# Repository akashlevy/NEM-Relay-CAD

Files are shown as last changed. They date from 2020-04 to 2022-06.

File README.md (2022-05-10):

# Stanford Accelerate NEM Relay Models

This repository contains almost everything a researcher might need to get started with NEM relays (MEM relays): (1) a parametric layout generator with KLayout, (2) finite elment models (FEM) with COMSOL/ANSYS, (3) static/dynamic compact model generators with SPICE/Verilog-A (and validation in Mathematica), (4) scripts for characterization with Synopsys SiliconSmart to produce Liberty files for VLSI flows.

A video tutorial of the COMSOL model is available: https://www.youtube.com/watch?v=YCjhU6pspo0

Also, read this paper for more info on potential applications of these models: https://ieeexplore.ieee.org/document/9712515

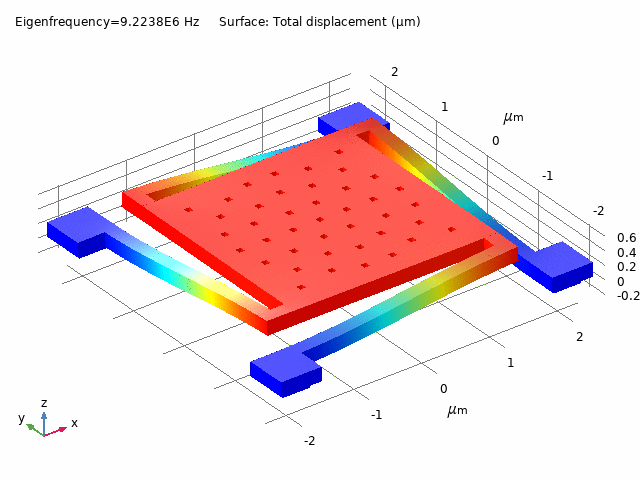
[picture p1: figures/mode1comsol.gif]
Modal Analysis in COMSOL


## Step 1: Configure NEM relay parameters

The configuration file `params.json` controls the relay dimensions and model parameters. Descriptions of the parameters are in `helper/params_desc.json`. `contpts.json` controls the locations of the contacts. To initialize contact placement to a circle, this file can be deleted.

## Step 2: KLayout NEM relay layout generator

Please use `pip install klayout` to install the Python API for KLayout. You can also install the KLayout GUI (https://www.klayout.de/), which may help with layout visualization.

Running `cd layouts; python relay.py` will generate layouts in DXF, GDSII, and CIF format based on the parameters in `params.json`. It will also generate `comsol/contpts.txt` which can be loaded into COMSOL in the next step.

You can also get predictions of the pull-in/pull-out voltages and parasitic capacitances based on the parallel-plate model by running `python handcalcs.py`. This will use the params specified in `params.json` to calculate and print these numbers.

SIDE NOTE: when we wanted to use the layout with Virtuoso, we combined layers in KLayout by doing layer operations: layer 6 = layer 6 - layer 7 + layer 8.

## Step 3: Finite element modeling (FEM)

### COMSOL model

To begin, run `python comsol_preproc.py` to generate `params.txt`. Then, load the parameters into COMSOL:
1. Under `Global Definitions/Parameters/Relay Parameters`, clear, load from file and select `comsol/params.txt`.
2. Under `Global Definitions/Parameters/Contact Placement`, clear, load from file and select `comsol/contpts.txt`.

NOTE: you may have to slightly modify the parameters once they have been loaded, since COMSOL has a bug where it does not automatically update the relay selections.

The COMSOL model has 5 studies that predict the physics of the multi-pole NEM relay. These are:
1. Spring Constant: determine spring constant by applying force to plate
2. Modal Analysis: determine eigenmodes and shapes
3. Parasitic Extraction: extract parasitic mutual capacitances between all terminals
    - A hacky way to get approximate parasitic extraction in the ON state is to set g_act = t_cont and gaptol = 1nm
4. Quasi-Static Sweep: find pull-in and pull-out voltages, contact forces, displacement contour, etc.
5. Transient Sweep: find out pull-in speed

Once these have been computed, you can view the results:
1. Mutual capacitances between all terminals
2. Eigenmode shape
3. Parasitic extraction potential plot
4. Contact placement and displacement contour plot
5. Quasi-static sweep plot
6. Transient sweep plot
7. Mechanical properties (spring constant, mass, eigenfrequencies)
8. Contact force for each contact

You can export the parameters as well for iterative contact placement and SPICE modeling.

For quasi-static sweep, you will have to choose a point on the relay to compute the displacement for. An arbitrary point on any of the contacts should work well.

For iterative contact placement, make sure to run the quasi-static sweep, then choose an operating voltage and displacement contour to extract, then export the displacement contour points. Then, run `python contpts.py` to get the next set of contacts (modify the parameters internally, if necessary, first). This generates `contpts.json`, which is used by `layouts/relay.py` to generate a new layout using the contact placement.

For SPICE modeling, make sure to run `python comsol_postproc.py`, which generates `spice/tech_params.va`. These parameters are used by the Verilog-A model.

### ANSYS model (unfinished, skip this for now)

There is an unfinished ANSYS 2020 Workbench model. It builds the NEM relay geometry using a SpaceClaim script. More work would be needed for this model to accurately predict anything, but it may serve as a good starting point/reference for people trying to model a NEM relay in ANSYS (although COMSOL is better than ANSYS at accurately modeling coupled interactions).

## Step 4: Compact modeling

### SPICE/Verilog-A model

The Verilog-A model is adapted from "Micro-Relay Technology For Energy-Efficient Integrated Circuit" (Hei Kam, Fred Chen) and is designed for use with SPECTRE or HSPICE. It has only been tested with HSPICE 2017.03, but it may also work with other SPICE simulators if simulation settings are adapted correctly.

There are three settings specific to the Verilog-A model in `params.json`. There is the Q-factor damping `Qf`, contact resistance `Rcont`, and air resistance `Rair`. These should be adjusted before simulation. All parameters are taken from the COMSOL model export: `comsol_postproc.py` must be run to generate `models/tech_params.va` that is used to define the simulation parameters.

The first thing to do is generate your Verilog-A model based on the number of bits you want to route with a single relay. You can do this by going into the `spice/` directory and running `python relay_gen.py {N}` where `N` is the number of bits to route. This will generate the Verilog-A file in the `models/` subdirectory called `nem_relay_{N}b.va` and quasistatic/transient SPICE testbenches in `test/` subdirectory. Running these simulations will verify the functionality of the relays by toggling them to see the quasistatic (slow sweep) and transient (fast sweep) response curves. Use `cscope` and export waveform data to do `plots.py` plotting.

Next, you can generate one-hot multiplexers from the NEM relays and test these as well. The first step is to run `python ohmux_gen.py {N} {M}`, where `N` is the number of bits to route, and `M` is the number of inputs to the multiplexer. This will generate several files: a SPICE model for the multiplexer without buffering (`models/nem_ohmux_{M}i_{N}b.sp`), a SPICE model for the multiplexer with an inverter to buffer the signal (`models/nem_ohmux_invd{D}_{M}i_{N}b.sp`), testbenches for both of these (`test/ohmux_test_{M}i_{N}b.sp`, `test/ohmux_test_invd{D}_{M}i_{N}b.sp`), and finally an instance file (`liberty/control/nem_ohmux_invd{D}_{M}i_{N}b.inst`) that can be used to characterize the SPICE model with SiliconSmart. By default, the inverter is taken from TSMC40 library through `tsmc40inc.sp`; using a different inverter is a matter of swapping out the implementation. The inverter drive strength can be specified through a command-line option e.g. `python ohmux_gen.py 1 2 -D1` will create a D1 inverter, and the area of a signle inverter can optionally be specified with `--area` option. The inverter area will be automatically multiplied by the number of bits to get the total area.

TODO: non-one-hot multiplexers

### Liberty model

The Liberty model generation has been tested with SiliconSmart M-2017.03-2. Library Compiler (LC) also needs to be loaded to compile the Liberty (.lib) files to DB (.db) files. In order to use SiliconSmart, first create the SPICE models in the previous step. Then simply run `siliconsmart run.tcl` to run the characterization flow. This will generate the library with all the .libs and .dbs necessary for a standard EDA flow. To debug, see the SPICE simulations for the different characterizations.

### Mathematica model (validation only)

Running the Mathematica notebook will solve the damped ODE model of the NEM relay and yield the transient displacement curve. It is good for validating the effect of Q-factor damping.

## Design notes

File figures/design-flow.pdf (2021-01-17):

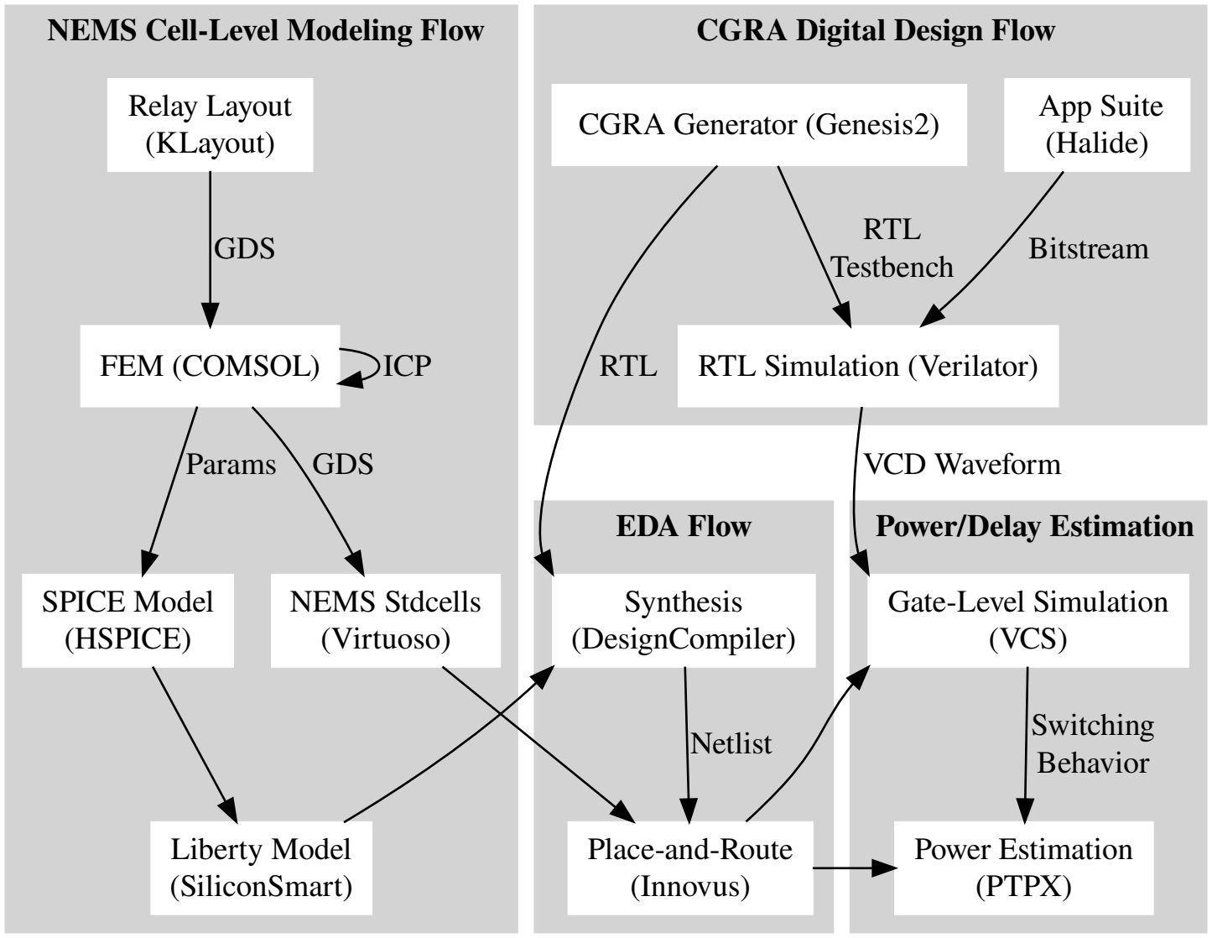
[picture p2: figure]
NEMS Cell-Level Modeling Flow; CGRA Digital Design Flow; EDA Flow; Power/Delay Estimation; Relay Layout (KLayout); FEM (COMSOL); GDS; ICP; SPICE Model (HSPICE); Params; NEMS Stdcells (Virtuoso); Liberty Model (SiliconSmart); Synthesis (DesignCompiler); Place-and-Route (Innovus); App Suite (Halide); RTL Simulation (Verilator); Bitstream; Gate-Level Simulation (VCS); VCD Waveform; CGRA Generator (Genesis2); RTL Testbench; RTL; Netlist; Power Estimation (PTPX); Switching Behavior

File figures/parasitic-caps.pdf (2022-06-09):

## Capacitance CCB:

## Capacitance CGB:

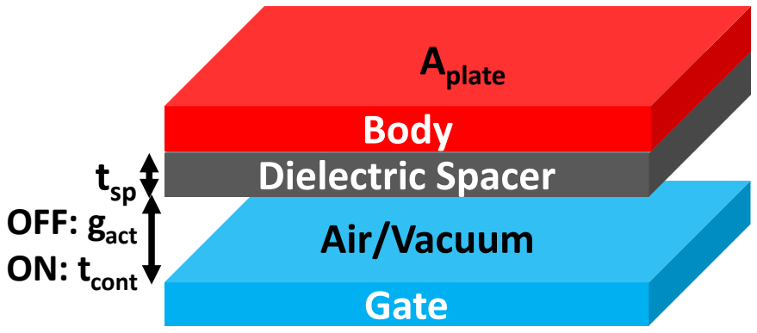
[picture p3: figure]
Gate; Dielectric Spacer; Body; OFF: gact ON: tcont; Aplate; Air/Vacuum; tsp
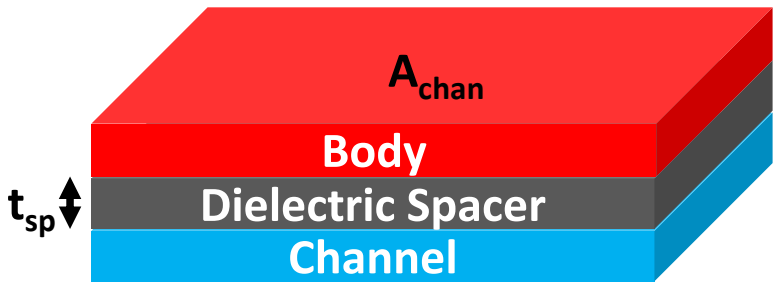
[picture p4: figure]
Channel; Dielectric Spacer; Body; tsp; Achan
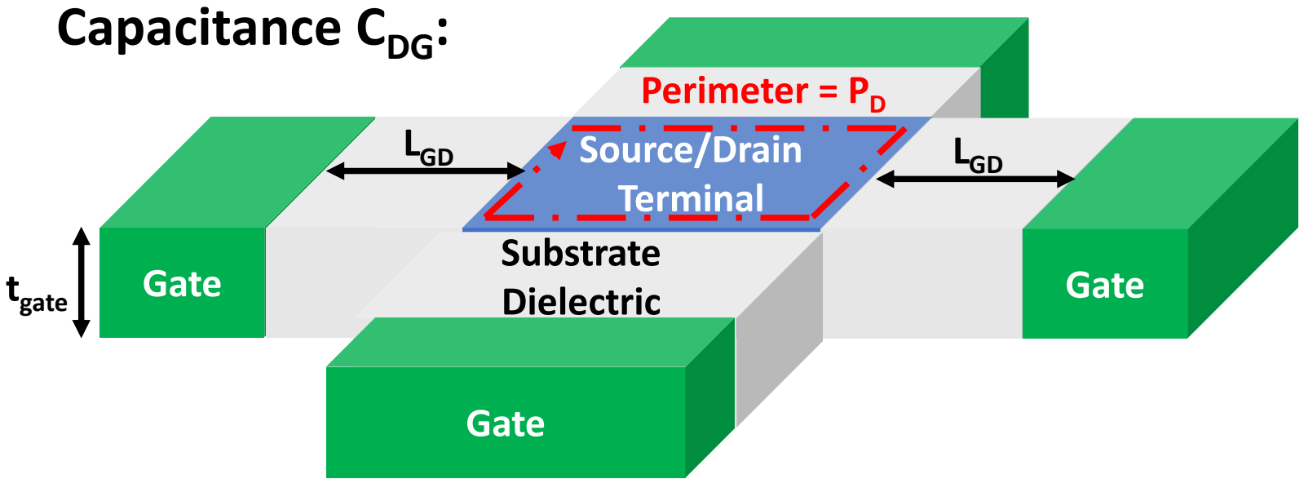
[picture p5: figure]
Gate; tgate; Source/Drain Terminal; Substrate Dielectric; Perimeter = PD; LGD; Capacitance CDG:

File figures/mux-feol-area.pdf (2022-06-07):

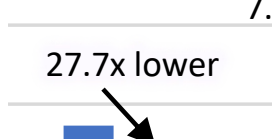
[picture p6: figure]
27.7x lower

2-input 8b
Mux

4-input 8b
Mux

10-input 8b
Mux

FEOL Area (a.u.)

CMOS NEMS

7.5x lower

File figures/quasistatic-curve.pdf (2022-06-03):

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

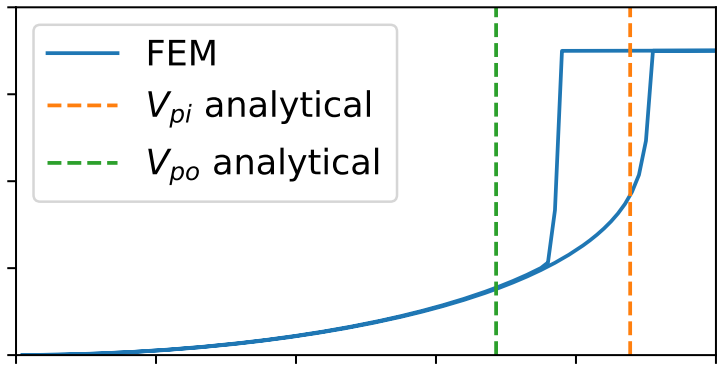
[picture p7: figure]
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

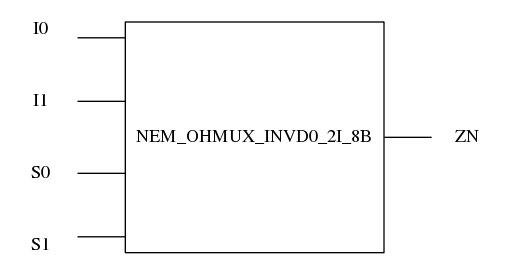
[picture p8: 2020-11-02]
liberty/nems40tt/reports/datasheets/images/nem_ohmux_invd0_2i_8b.png

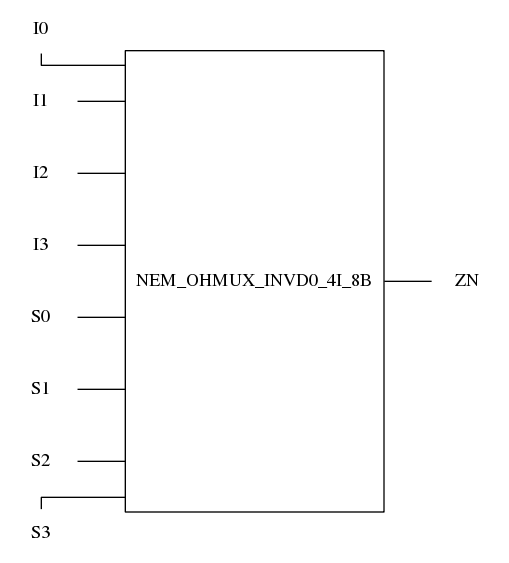
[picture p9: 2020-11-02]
liberty/nems40tt/reports/datasheets/images/nem_ohmux_invd0_4i_8b.png

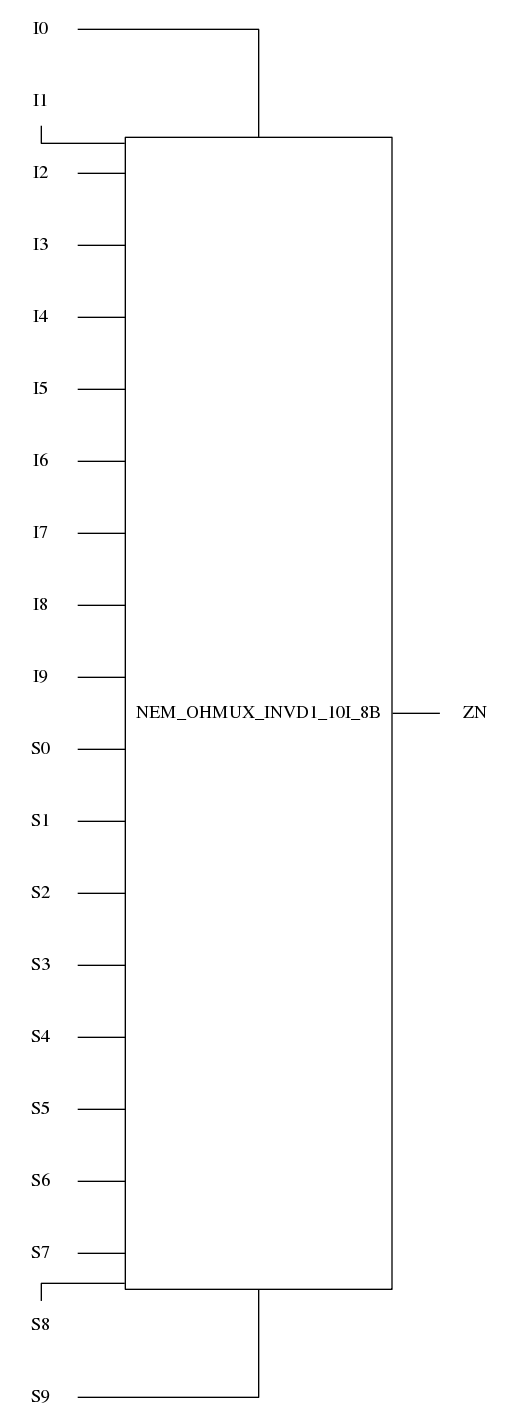
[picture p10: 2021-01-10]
liberty/nems40tt/reports/datasheets/images/nem_ohmux_invd1_10i_8b.png

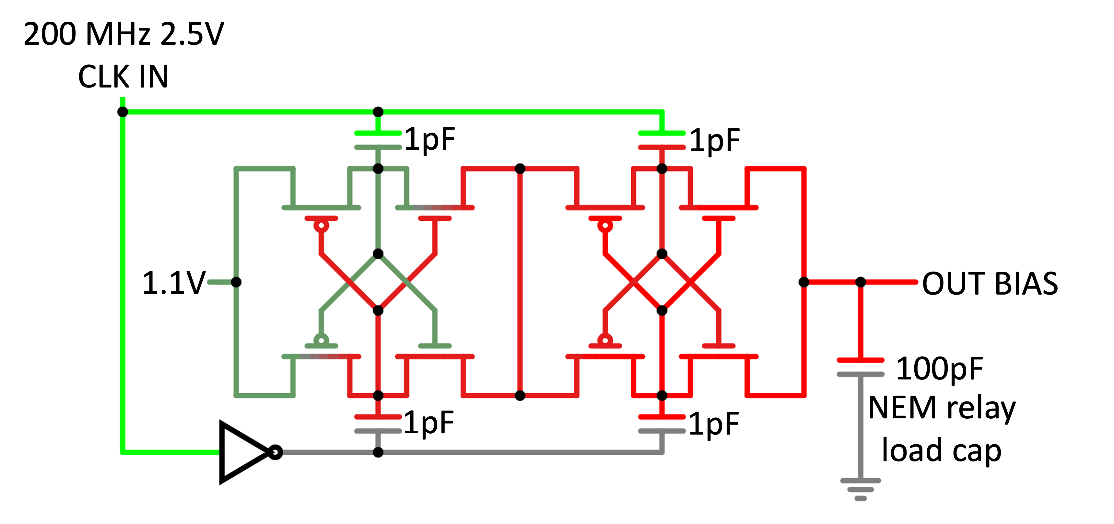
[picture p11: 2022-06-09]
figures/cccp-hor-labeled.png

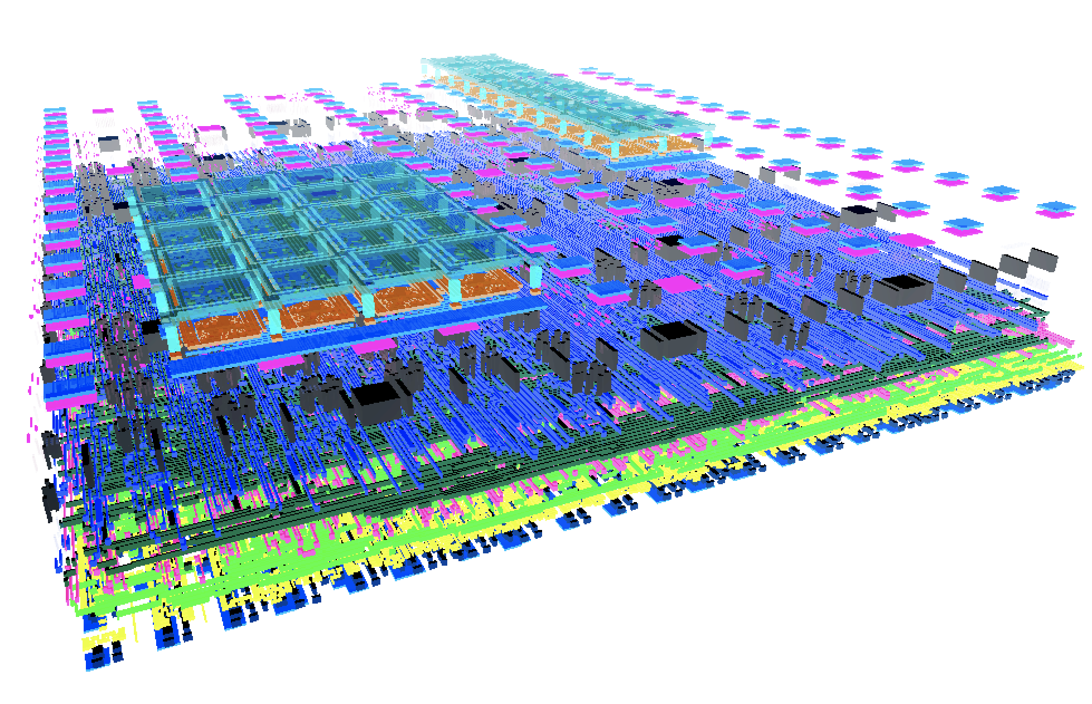
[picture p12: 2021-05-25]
figures/3d-cgra-light.png

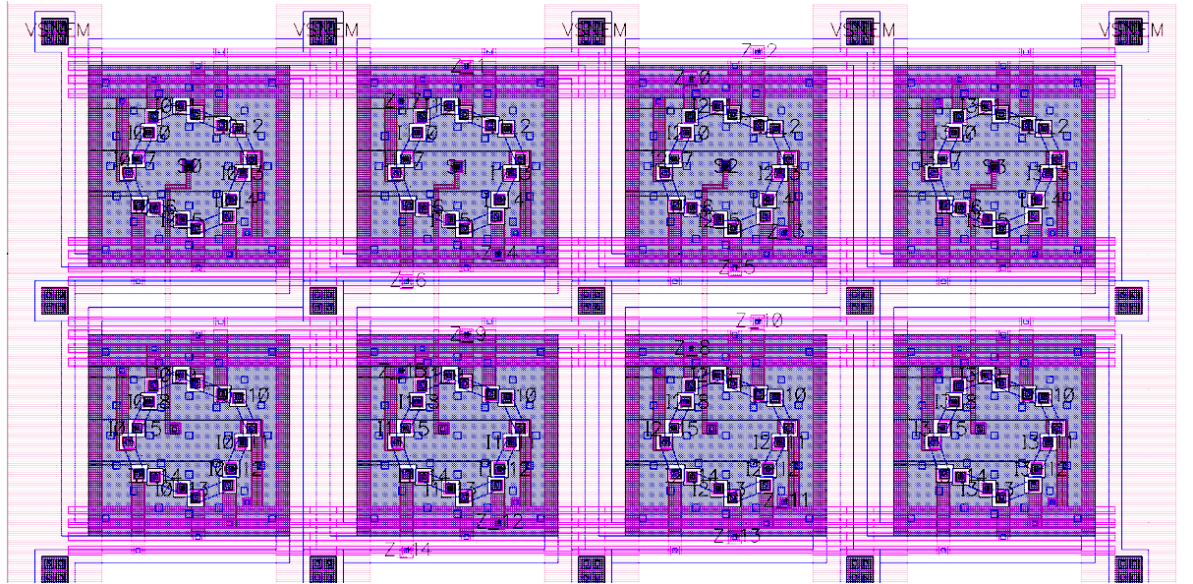
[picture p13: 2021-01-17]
figures/4to1muxinv.png

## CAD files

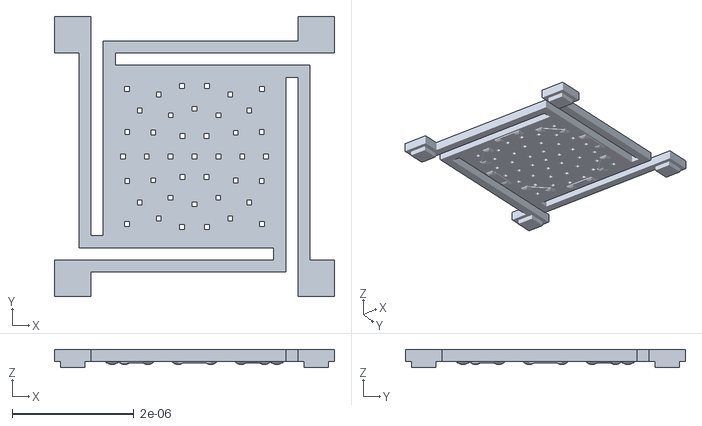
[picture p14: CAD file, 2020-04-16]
figures/mesh.stl
4.6e-06 x 4.6e-06 x 3e-07

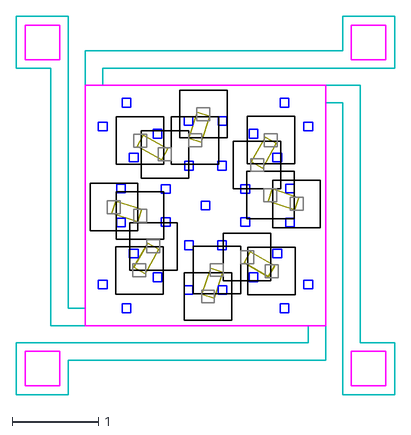
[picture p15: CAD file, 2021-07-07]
layouts/relay.dxf
4.38 x 4.38

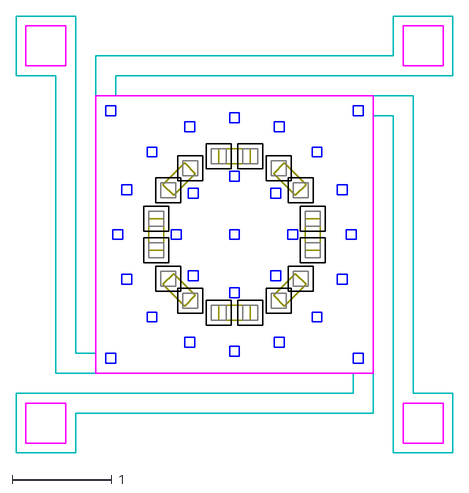
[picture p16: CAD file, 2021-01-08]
output/iter0/relay.dxf
4.38 x 4.38

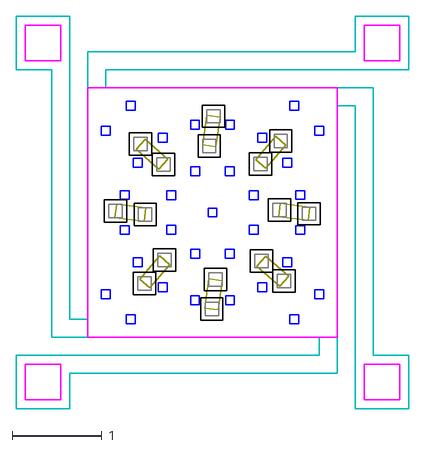
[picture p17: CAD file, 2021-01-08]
output/iter2/relay.dxf
4.38 x 4.38

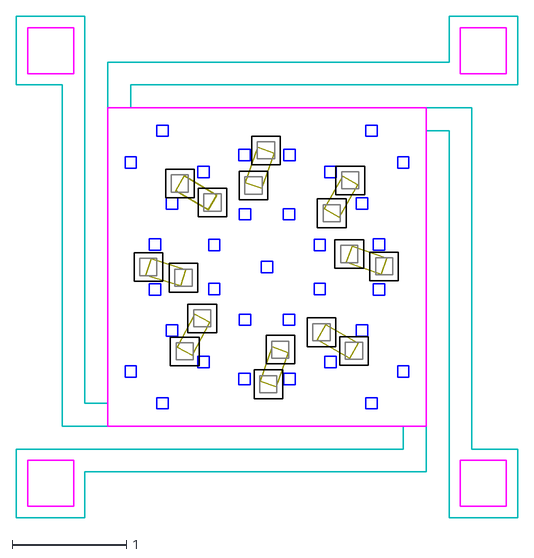
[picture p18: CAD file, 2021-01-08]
output/iter3/relay.dxf
4.38 x 4.38

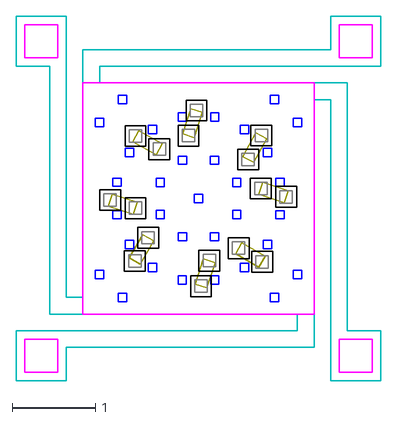
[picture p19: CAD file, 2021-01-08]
output/iter4/relay.dxf
4.38 x 4.38

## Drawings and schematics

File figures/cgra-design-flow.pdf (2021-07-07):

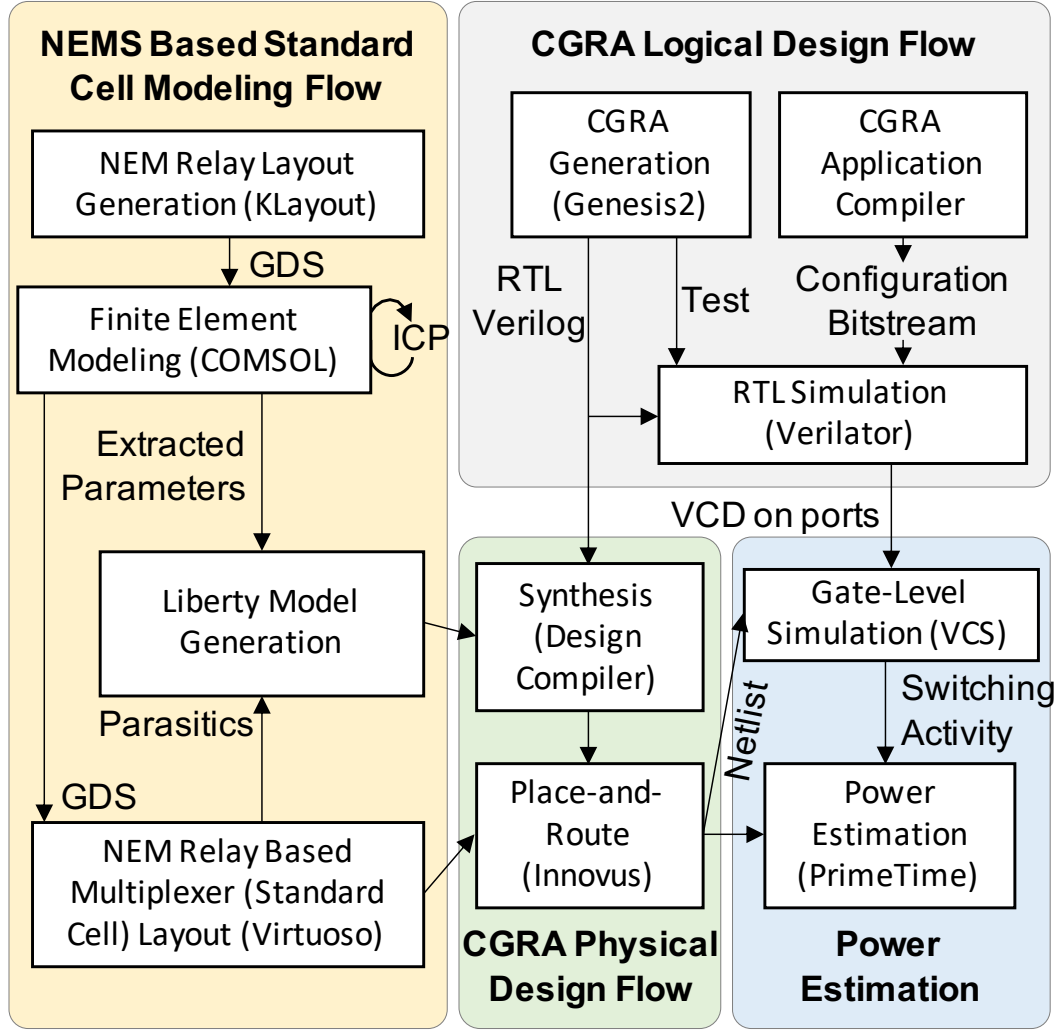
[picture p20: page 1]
Liberty Model Generation; CGRA Application Compiler; Test RTL Verilog; RTL Simulation (Verilator); Synthesis (Design Compiler); Place-and- Route (Innovus); Gate-Level Simulation (VCS); Power Estimation (PrimeTime); CGRA Physical Design Flow; Power Estimation; Switching Activity; Extracted Parameters; GDS; Netlist; Finite Element; Modeling (COMSOL); ICP; Configuration Bitstream

NEMS Based Standard
Cell Modeling Flow
NEM Relay Layout
Generation (KLayout)

CGRA Logical Design Flow
CGRA
Generation
(Genesis2)

VCD on ports

Parasitics
GDS
NEM Relay Based
Multiplexer (Standard
Cell) Layout (Virtuoso)

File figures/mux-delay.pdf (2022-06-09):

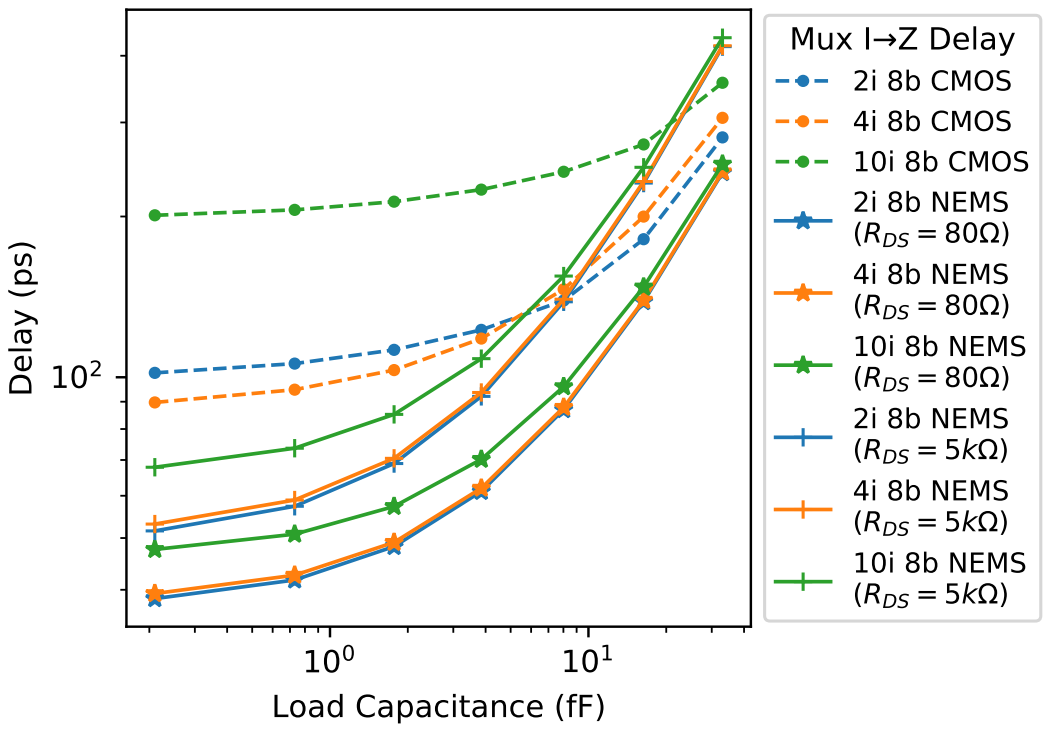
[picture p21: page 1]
1 Load Capacitance (fF); Delay (ps); Mux I Z Delay 2i 8b CMOS 4i 8b CMOS 10i 8b CMOS 2i 8b NEMS (RDS = 80 ); 4i 8b NEMS (RDS = 80 ); 10i 8b NEMS (RDS = 80 ); 2i 8b NEMS (RDS = 5k ); 4i 8b NEMS (RDS = 5k ); 10i 8b NEMS (RDS = 5k )

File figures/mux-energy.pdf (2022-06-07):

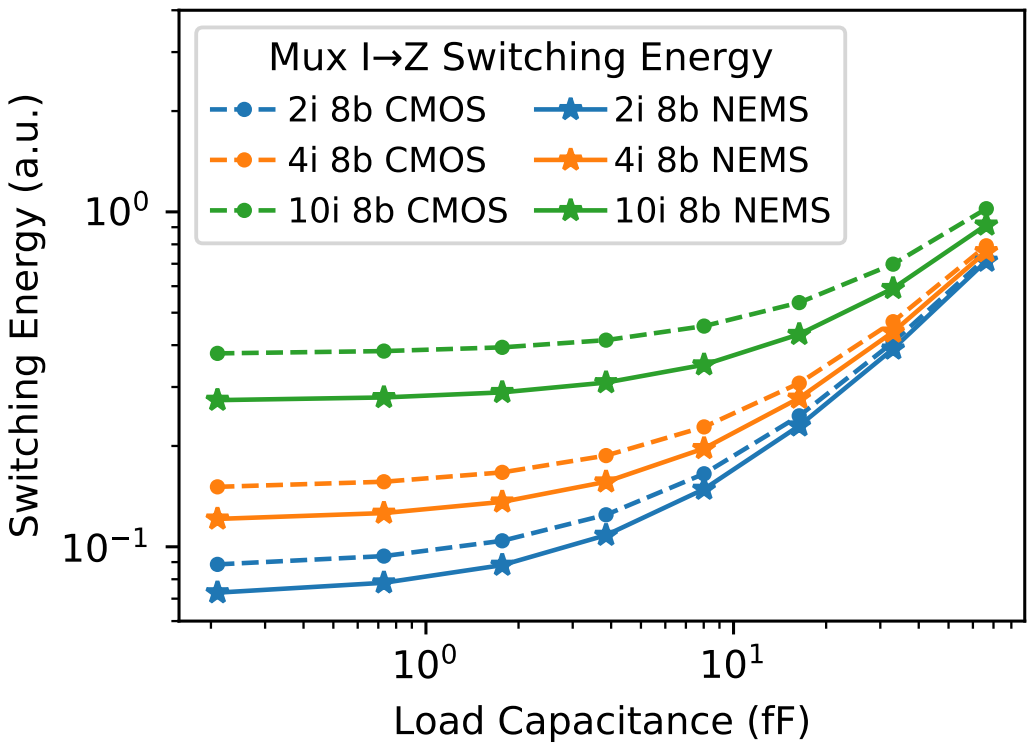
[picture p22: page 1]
Switching Energy (a.u.); 2i 8b NEMS 4i 8b NEMS 10i 8b NEMS

Mux I Z Switching Energy
2i 8b CMOS
4i 8b CMOS
10i 8b CMOS

Load Capacitance (fF)

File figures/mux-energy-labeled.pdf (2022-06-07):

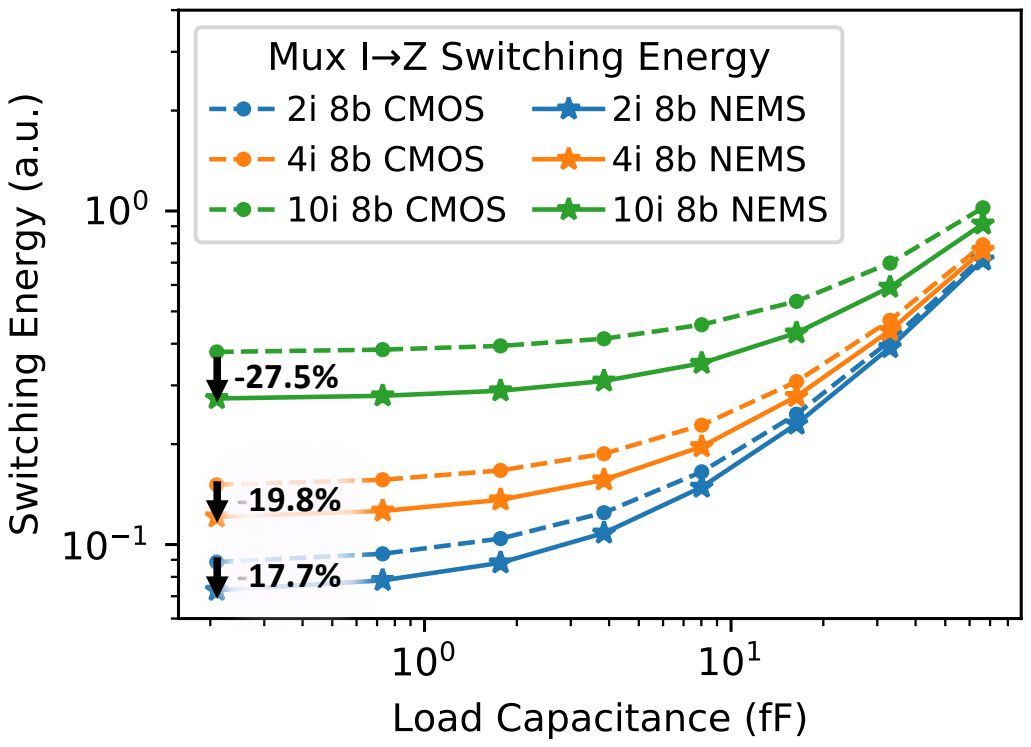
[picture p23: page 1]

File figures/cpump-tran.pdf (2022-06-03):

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

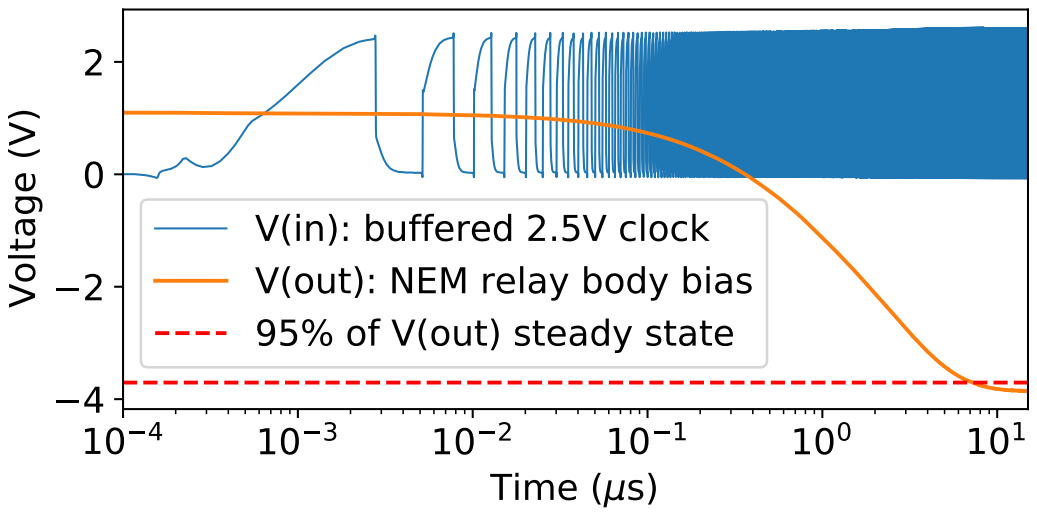
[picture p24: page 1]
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

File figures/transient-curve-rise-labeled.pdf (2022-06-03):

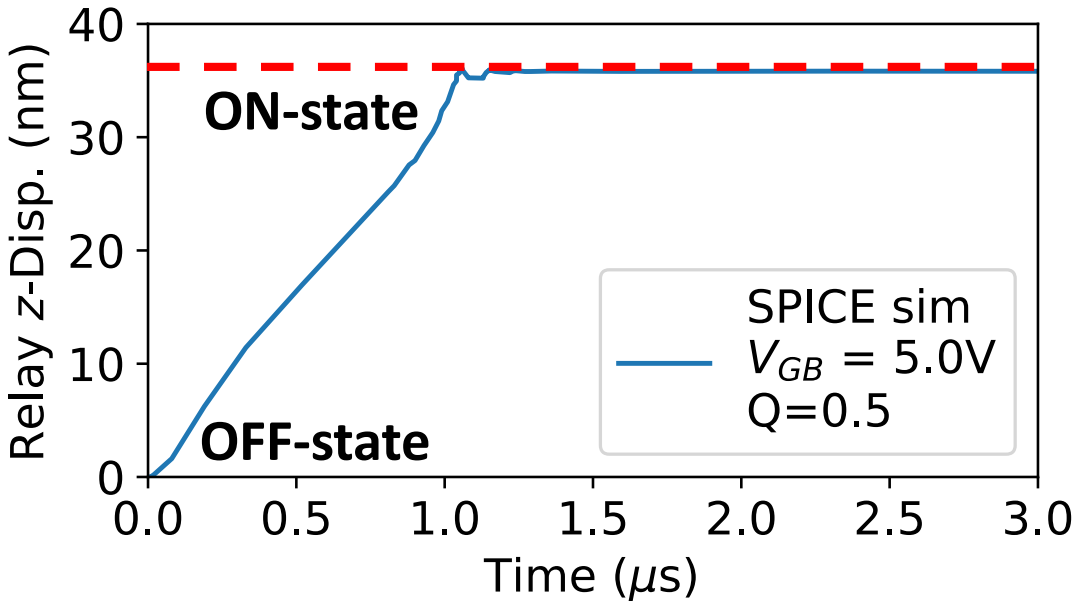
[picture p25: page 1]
ON-state; OFF-state

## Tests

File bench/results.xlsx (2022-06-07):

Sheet: Area Minimized Results
 | Load Cap (pF) | 0.00021
 | Driver Strength: | D0 | D1 | D2 | D3 | D4 | D6 | D8 | D12 | D16 | D20 | D24
2-Input 8b CMOS Mux | I->Z Delay (ns) |  |  | 0.0992016
 | S->Z Delay (ns) |  |  | 0.1855637
 | I->Z Power (W) |  |  | 3.94e-06
 | S->Z Power (W) |  |  | 1.73e-06
 | IS->Z Power (W) |  |  | 5.02e-06
 | Leakage Power (W) | 8.95e-10
 | CMOS Area (um^2) | 14.6412
 | NEMS Area (um^2) | 0
4-Input 8b CMOS Mux | I->Z Delay (ns)
 | S->Z Delay (ns)
 | I->Z Power (W)
 | S->Z Power (W)
 | Leakage Power (W) | 1.64e-09
 | CMOS Area (um^2) | 29.2824
 | NEMS Area (um^2) | 0
10-Input 8b CMOS Mux | I->Z Delay (ns)
 | S->Z Delay (ns)
 | I->Z Power (W)
 | S->Z Power (W)
 | Leakage Power (W) | 4.47e-09
 | CMOS Area (um^2) | 80.262
 | NEMS Area (um^2) | 0
2-Input 8b NEM Mux | I->Z Delay (ns)
 | S->Z Delay (ns) | 1000 | 1000 | 1000 | 1000 | 1000 | 1000 | 1000 | 1000 | 1000 | 1000 | 1000
 | I->Z Power (W)
 | S->Z Power (W)
 | Leakage Power (W)
 | CMOS Area (um^2) | 0.5292
 | NEMS Area (um^2) | 28.5768
4-Input 8b NEM Mux | I->Z Delay (ns)
 | S->Z Delay (ns) | 1000 | 1000 | 1000 | 1000 | 1000 | 1000 | 1000 | 1000 | 1000 | 1000 | 1000
 | I->Z Power (W)
 | S->Z Power (W)
 | Leakage Power (W)
 | CMOS Area (um^2) | 3.8808
 | NEMS Area (um^2) | 57.1536
10-Input 8b NEM Mux | I->Z Delay (ns)
 | S->Z Delay (ns) | 1000 | 1000 | 1000 | 1000 | 1000 | 1000 | 1000 | 1000 | 1000 | 1000 | 1000
 | I->Z Power (W)
 | S->Z Power (W)
 | Leakage Power (W)
 | CMOS Area (um^2) | 13.9356
 | NEMS Area (um^2) | 142.884
Delays and energies include buffer
Areas do not include buffer
Leakage power does not include buffer

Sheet: Area Plot
Area | CMOS | NEMS
2-input 8b Mux | 14.6412 | 0.5292 | 27.66666667
4-input 8b Mux | 29.2824 | 3.8808 | 7.545454545
10-input 8b Mux | 80.262 | 13.9356 | 5.759493671

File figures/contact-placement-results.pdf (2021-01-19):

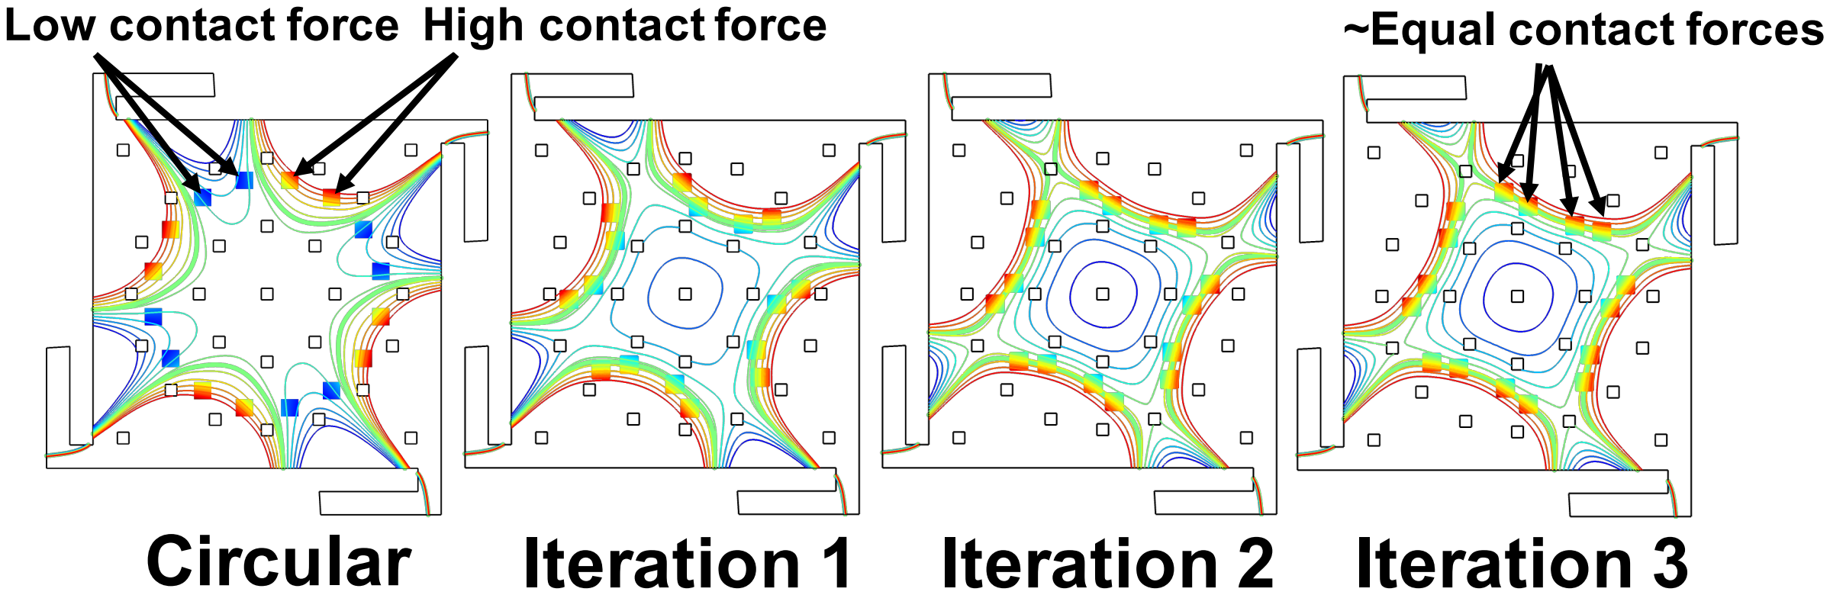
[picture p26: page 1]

Circular | Iteration 1 Iteration 2 Iteration 3
Low contact force High contact force | ~Equal contact forces

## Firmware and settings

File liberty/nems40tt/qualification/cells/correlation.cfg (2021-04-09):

check none
do none
ca 0
lc /cad/synopsys/lc/M-2017.06-SP3/bin/lc_shell
lcc 
pt 
sim 
net /sim/akashl/NEM-Relay-CAD/liberty/nems40tt/netlists
ext 
pdr 0.5
dr 
cl 0
agg 
corr 0
opt 
l1 0
fs 0
comp 11
pg 
s 
c 
gp gnuplot
ts 1000
mc -1
mcc 
mcp 
ts 1000

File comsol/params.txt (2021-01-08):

L_plate 2.7800000000000002[um] "Side length of relay plate"
L_cant 2.7800000000000002[um] "Length of cantilever beam"
L_cont 149.99999999999997[nm] "Side length of contact"
L_hole 99.99999999999999[nm] "Side length of release hole"
L_via 399.99999999999994[nm] "Side length of via"
L_anc 599.9999999999999[nm] "Side length of anchor extension"
W_cant 199.99999999999997[nm] "Width of cantilever beam"
g_cant 199.99999999999997[nm] "Gap between cantilever beam and relay body"
g_land 49.99999999999999[nm] "Gap for spacing between landing pads and gate"
r_hole_pl 1170.0[nm] "Radius along which to place holes"
d_hole_pl 199.99999999999997[nm] "Diameter along which to place holes"
t_poly 119.99999999999999[nm] "Thickness of poly"
t_cont 24.999999999999996[nm] "Thickness of contact"
t_sp 29.999999999999996[nm] "Thickness of spacer"
t_chan 10.0[nm] "Thickness of channel"
t_sub 499.99999999999994[nm] "Thickness of substrate"
t_gap 59.99999999999999[nm] "Gap between poly body and substrate"
Qf 0.5 "Quality factor of relay motion"
Rcont 1000.0[ohm] "Contact resistance"
Rair 1000000000000000.0[ohm] "Air resistance"
K_sp 5.7 "Relative permittivity of dielectric spacer"
g_act 59.99999999999999[nm] "Gap between poly body and substrate"

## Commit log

2019-11-30 New version
    [relay.scad, relay_default.stl]
2019-12-02 Hand calculations, plots, and default model
    [relay.scad]
2019-12-09 A lot of updates
    [L_plate_10.000.stl, L_plate_3.000.stl, L_plate_4.000.stl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]
2020-02-05 More realistic relay parameters for CGRA
    [cont.dxf, poly.dxf, relay.scad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]
2020-02-05 Add layouts
    [cont.dxf, poly.dxf, vias.dxf]
2020-02-19 Fix scaling, add landing contacts
    [chan.dxf, land.dxf, relay.scad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]
2020-03-06 KLayout migration
    [relay.dxf, relay.scad]
2020-03-06 STEP file
    [relay.step]
2020-03-06 More stuff
    [nemanc.dxf, nembody.dxf, nembody.step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]
2020-03-06 STEP files
    [nemanc.step, nembody.step]
2020-03-06 dxf better
    [nemanc.dxf, nembody.dxf, nemchan.dxf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]
2020-03-07 Fix DXF
    [nemanc.dxf, nembody.dxf, nemchan.dxf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]
2020-03-10 Updated layouts
    [nemanc.dxf, nemanc.step, nembody.dxf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]
2020-03-10 New layout
    [relay.dxf]
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2020-04-05 Working analyses
    [emt_config.txt]
2020-04-15 Updated geometry, scripts, and materials
2020-04-16 New imgs
    [mesh.stl]
2020-04-29 Updated relay for substrate and added images
    [relay.dxf]
2020-04-29 Split into more layers
    [relay.dxf]
2020-05-01 Moving things and comsol postproc
    [emt_config.txt]
2020-05-26 Relay contact balance
    [contforce.csv, contforce2.csv, relay.dxf]
2020-05-27 Klayout updates
    [contforce3.csv, relay.dxf]
2020-05-30 Relay merged layout
    [relay_merged.dxf]
2020-06-02 Remove symmetry material properties
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2020-06-13 generates verilog-a file for relay w given number of bits
2020-09-26 Remove 3D parameters from relay.py
2020-09-27 Commit a lot of stuff
    [mechprops.csv, mutualcaps.csv, relay_merged.dxf]
2020-09-29 Done updating
    [params.txt]
2020-09-29 Relay added
    [fcont.csv]
2020-09-30 Contact placement method and other things
    [dispcont.csv, relay.dxf]
2020-10-06 Lots of changes
    [contact-placement.xlsx, dispcont.csv, fcont.csv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]
2020-10-06 Small changes to relay
2020-10-06 Fix NEM relay equation
2020-10-06 Fix to resistance
2020-10-06 Fixes to current equation
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2020-10-06 Fix contact resistance problem
2020-10-06 Move stuff and minor changes
    [dispcont.csv, fcont.csv, mechprops.csv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]
2020-10-06 Newer data
    [dispcont.csv, fcont.csv, mechprops.csv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]
2020-10-06 SPICE simulations of a single relay
2020-10-12 Hand calcs use air, plots, relay updates
2020-10-12 SPICE models
    [contact-placement.xlsx, transient.csv]
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2020-10-15 Add power period statement to get better settling
2020-10-15 Turn off probe for easier debugging
2020-10-15 Improve simulation resolution and power period
2020-10-28 Try with VDD and gnd
2020-10-28 Switch to ohmux inst
2020-10-31 Added qualification and datasheets
    [correlation.cfg, index.csv]
2020-10-31 Fixing channel for n-bit relay
2020-10-31 Testing new relay models
2020-11-01 Remove old stuff and update mux gen for bundles
    [correlation.cfg, index.csv]
2020-11-02 Bundled characterizations
    [correlation.cfg, index.csv]
2020-11-17 Try resistive driver on test.lib
2020-12-04 Enable all instances to rerun overnight: working
    [correlation.cfg, index.csv]
2020-12-05 The library
    [correlation.cfg, index.csv]
2020-12-07 Let's try this again
    [correlation.cfg, index.csv]
2020-12-07 Switch to output voltage on feedthru pins
2020-12-07 Added new libs, no dbs
    [correlation.cfg, index.csv]
2020-12-08 Remove voltages for input/output of feedthru
2021-01-08 Smaller relay design
    [dispcont.csv, fcont.csv, mechprops.csv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]
2021-01-08 Switch VB to VSNEM
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2021-01-08 Remove old stuff
    [correlation.cfg, index.csv]
2021-01-10 Added results of SiSmart run
    [correlation.cfg, index.csv]
2021-01-14 Switch to ULP SPICE library
2021-01-17 Figures directory instead
    [contact-placement.xlsx, mesh.stl]
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2021-04-09 Add strong drive strength results
    [correlation.cfg]
2021-05-17 Added normalized driver waveform (NDW) from tsmc40
2021-05-17 Add consistent driver waveform with inverters
2021-05-18 Try just using the driver.db as default
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2021-05-18 Give it a shot and see if it uses driver.db
2021-05-18 Use the minimum on driver.db
2021-05-19 NEMS stuff
    [correlation.cfg, index.csv]
2021-05-20 Remove old results
    [correlation.cfg, index.csv]
2021-05-20 Try with power measure map
2021-05-20 Try power meas map instead
2021-05-20 Just ignore VSNEM in all power measurements
2021-05-20 Add lib files
    [correlation.cfg, index.csv]
2021-05-25 Lib file with right pin caps
2021-05-25 Change pin names to not get confused with inv case
2021-05-28 Need to add register input pin cap
2021-07-07 Update figures
    [table.xlsx]
2021-07-07 Update gap spacing everywhere
    [mutualcaps.csv, quasistatic.csv, relay.dxf]
2021-07-29 Figure updates
    [PPA.xlsx, contact-placement.xlsx]
2022-05-26 Charge pump and new area/PPA stuff
    [PPA.xlsx]
2022-05-26 Add charge pump to model
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2022-05-26 Try with 2.5V diode instead
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2022-05-26 Try new charge pump
2022-05-26 Try diode IV as well
2022-05-26 Try one stage charge pump
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2022-05-26 Try with 2.5V again to avoid voltage drop problem
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2022-05-26 Level shift with 2.5V
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2022-05-26 Charge pump transient simulation
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2022-05-27 Try charge pump again
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2022-06-04 Try ptpx script
    [results.xlsx]
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2022-06-04 Script to generate all results
    [results.xlsx]
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2022-06-06 Try setting 0 on case analysis for mux
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2024-06-08 Minor figure updates
    [PPA.xlsx]
